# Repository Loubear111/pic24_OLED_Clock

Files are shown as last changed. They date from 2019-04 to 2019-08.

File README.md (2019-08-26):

# pic24_OLED_Clock
A RTC and OLED project for the PIC24FJ64GA002 Microcontroller. This project uses the Adafruit 1.3" Monochrome OLED display as well as the RTC module on the PIC to create an interactive clock and stopwatch with alarm functions.
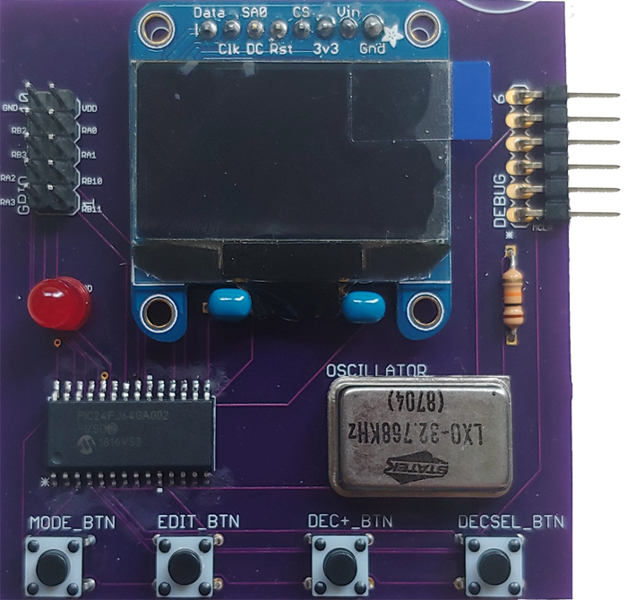
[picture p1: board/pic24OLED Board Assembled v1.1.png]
Board v1.1


**PIC24 Microcontroller** - https://www.microchip.com/wwwproducts/en/PIC24FJ64GA002 \
**Adafruit Display** - https://www.adafruit.com/product/938 \
**chipKIT Programmer** - https://store.digilentinc.com/chipkit-pgm-programmer-debugger-for-use-with-digilent-chipkit-platforms/

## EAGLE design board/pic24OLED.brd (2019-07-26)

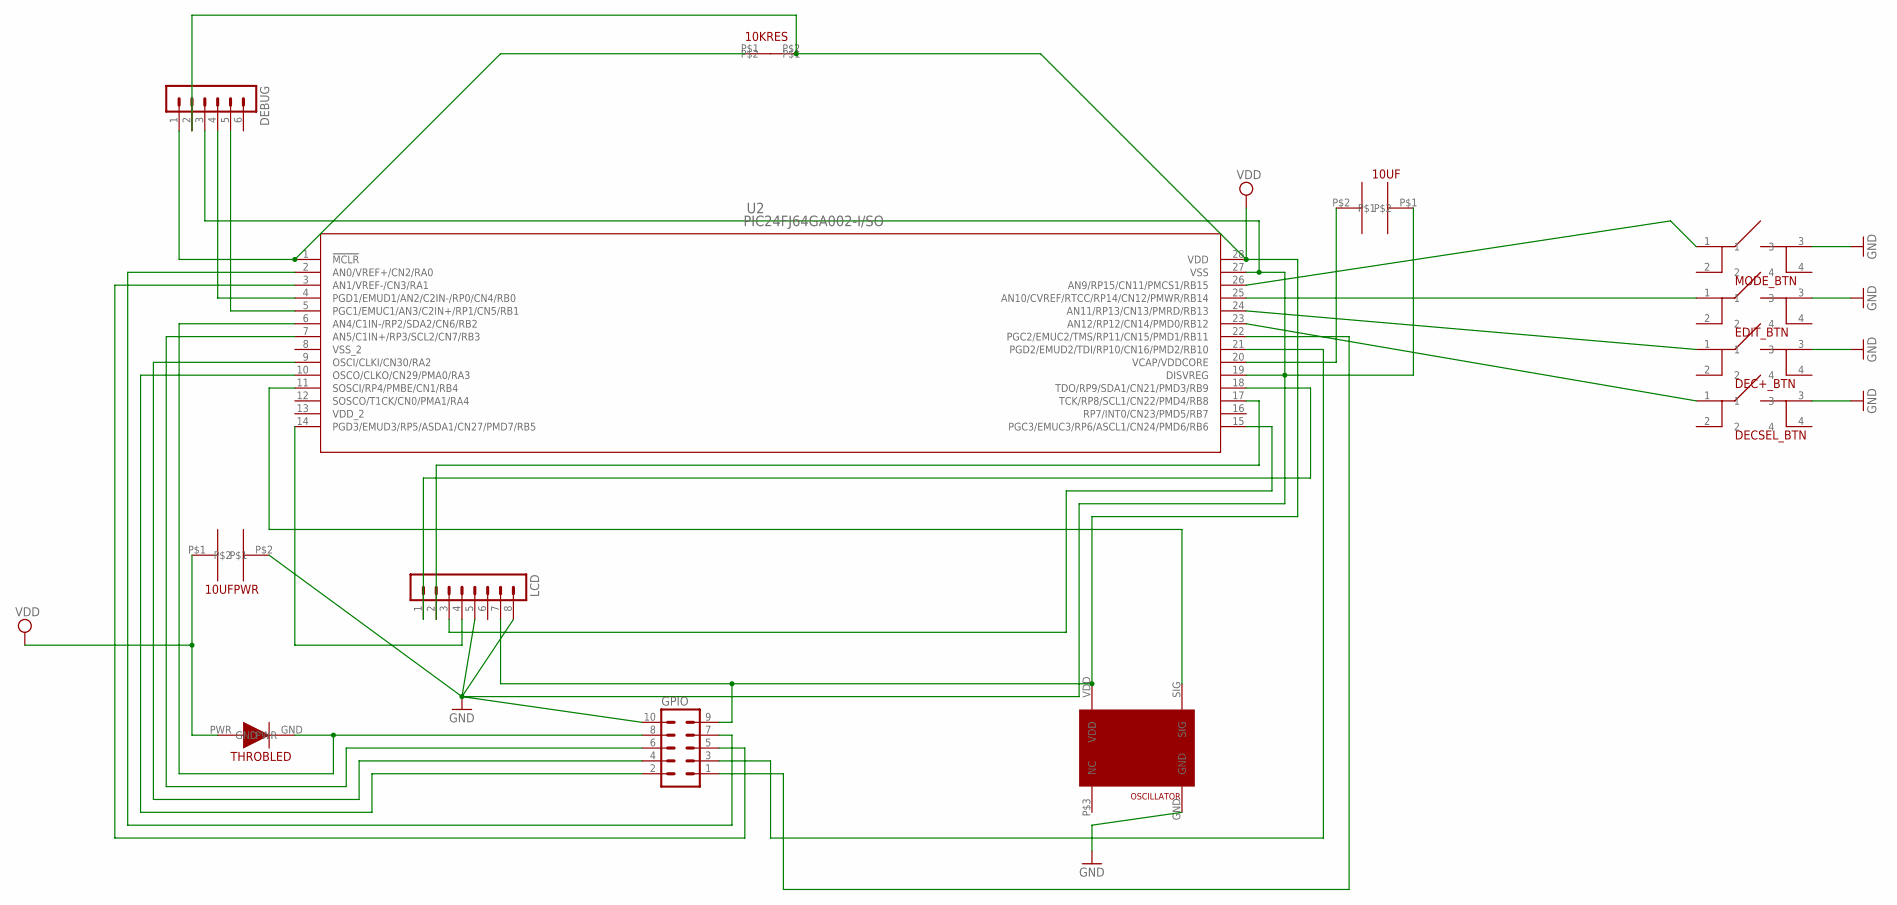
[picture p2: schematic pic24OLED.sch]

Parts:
10KRES: THRESISTOR
10UF, 10UFPWR: THCAP
DEBUG: MA06-1
DEC+_BTN: PTS645-BUTTONPTS645; TL3315-BUTTON
DECSEL_BTN: PTS645-BUTTONPTS645; TL3315-BUTTON
EDIT_BTN: PTS645-BUTTONPTS645; TL3315-BUTTON
GPIO: MA05-2
LCD: MA08-1
MODE_BTN: PTS645-BUTTONPTS645; TL3315-BUTTON
OSCILLATOR: LX0-32.768OSCILLATOR
THROBLED: THLED
U2: PIC24FJ64GA002-I/SO; SOIC28-W_MC

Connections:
GND: 10UF.P$1, 10UFPWR.P$2, DEBUG.3, DEC+_BTN.3, DECSEL_BTN.3, EDIT_BTN.3, GPIO.10, LCD.5, LCD.8, MODE_BTN.3, OSCILLATOR.GND, U2.19 (DISVREG), U2.27 (VSS)
unnamed: 10KRES.P$1, DEBUG.1, U2.1 (!MCLR)
unnamed: GPIO.4, U2.9 (OSCI/CLKI/CN30/RA2)
unnamed: MODE_BTN.1, U2.26 (AN9/RP15/CN11/PMCS1/RB15)
unnamed: EDIT_BTN.1, U2.25 (AN10/CVREF/RTCC/RP14/CN12/PMWR/RB14)
unnamed: DEC+_BTN.1, U2.24 (AN11/RP13/CN13/PMRD/RB13)
unnamed: DECSEL_BTN.1, U2.23 (AN12/RP12/CN14/PMD0/RB12)
unnamed: LCD.4, U2.14 (PGD3/EMUD3/RP5/ASDA1/CN27/PMD7/RB5)
unnamed: LCD.3, U2.15 (PGC3/EMUC3/RP6/ASCL1/CN24/PMD6/RB6)
unnamed: LCD.2, U2.17 (TCK/RP8/SCL1/CN22/PMD4/RB8)
unnamed: LCD.1, U2.18 (TDO/RP9/SDA1/CN21/PMD3/RB9)
unnamed: 10UF.P$2, U2.20 (VCAP/VDDCORE)
unnamed: GPIO.6, U2.7 (AN5/C1IN+/RP3/SCL2/CN7/RB3)
unnamed: OSCILLATOR.SIG, U2.11 (SOSCI/RP4/PMBE/CN1/RB4)
unnamed: GPIO.8, THROBLED.GND, U2.6 (AN4/C1IN-/RP2/SDA2/CN6/RB2)
unnamed: DEBUG.4, U2.4 (PGD1/EMUD1/AN2/C2IN-/RP0/CN4/RB0)
unnamed: DEBUG.5, U2.5 (PGC1/EMUC1/AN3/C2IN+/RP1/CN5/RB1)
unnamed: GPIO.2, U2.10 (OSCO/CLKO/CN29/PMA0/RA3)
unnamed: GPIO.7, U2.2 (AN0/VREF+/CN2/RA0)
unnamed: GPIO.5, U2.3 (AN1/VREF-/CN3/RA1)
unnamed: GPIO.3, U2.21 (PGD2/EMUD2/TDI/RP10/CN16/PMD2/RB10)
unnamed: GPIO.1, U2.22 (PGC2/EMUC2/TMS/RP11/CN15/PMD1/RB11)
VDD: 10KRES.P$2, 10UFPWR.P$1, DEBUG.2, GPIO.9, LCD.7, OSCILLATOR.VDD, THROBLED.PWR, U2.28 (VDD)

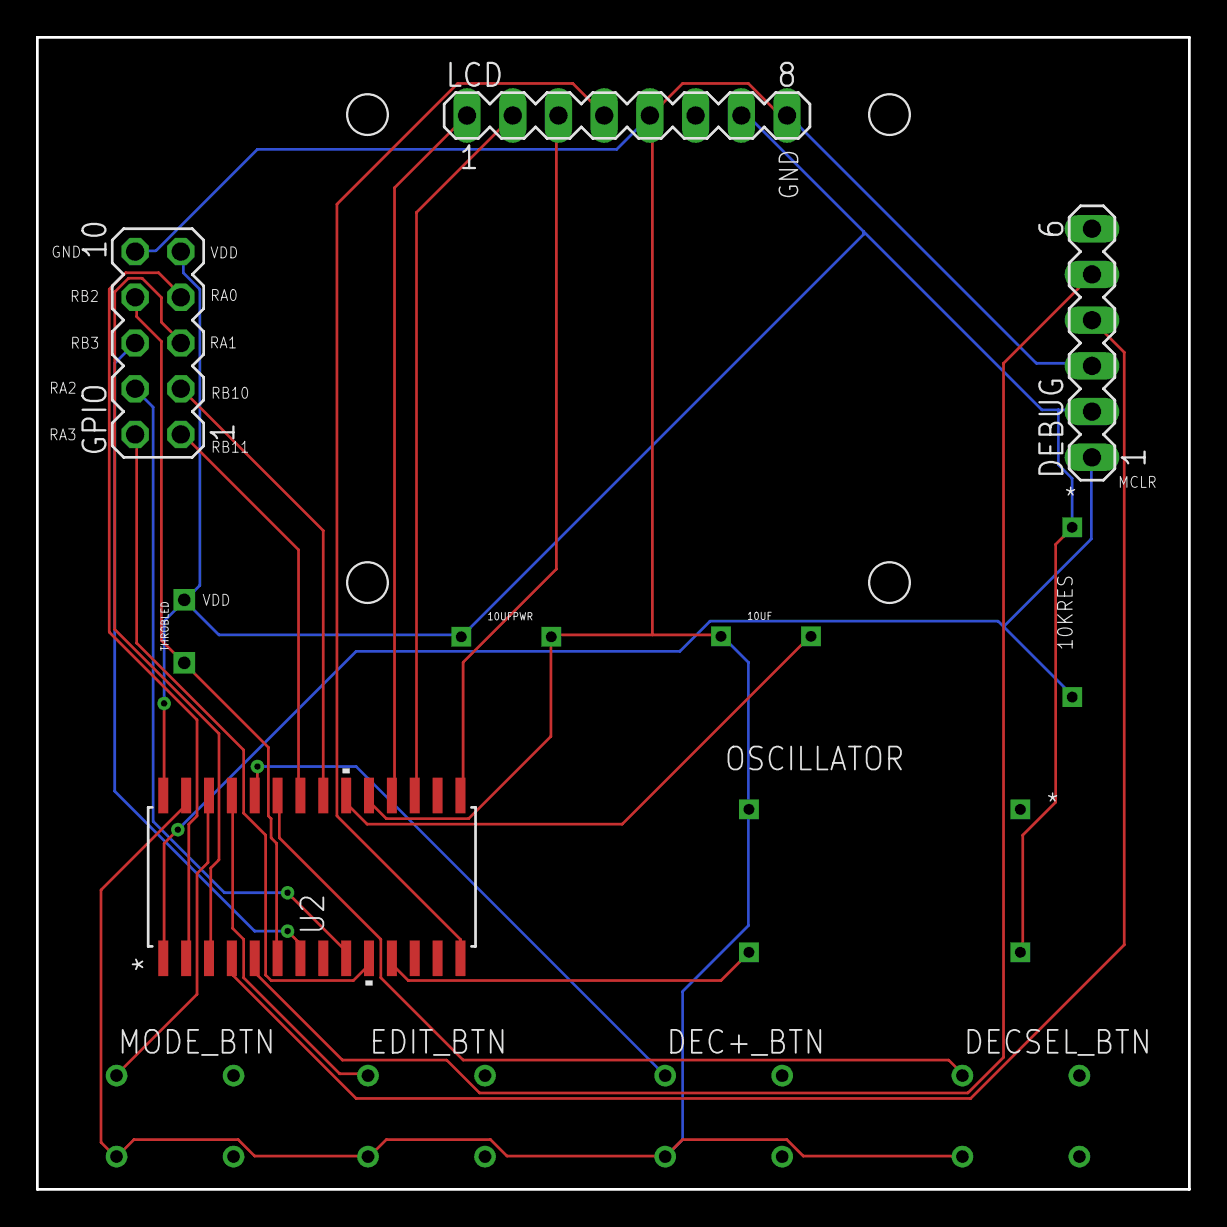
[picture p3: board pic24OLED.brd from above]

Board: 2 copper layers, 64.0 x 64.0 mm, 13 parts (0 on the bottom side), 23 nets.

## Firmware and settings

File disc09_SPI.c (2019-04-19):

#include <p24Fxxxx.h>
#include <xc.h>
#include <stdlib.h>

// PIC24FJ64GA002 Configuration Bit Settings
// CW1: FLASH CONFIGURATION WORD 1 (see PIC24 Family Reference Manual 24.1)
#pragma config ICS = PGx1          // Comm Channel Select (Emulator EMUC1/EMUD1 pins are shared with PGC1/PGD1)
#pragma config FWDTEN = OFF        // Watchdog Timer Enable (Watchdog Timer is disabled)
#pragma config GWRP = OFF          // General Code Segment Write Protect (Writes to program memory are allowed)
#pragma config GCP = OFF           // General Code Segment Code Protect (Code protection is disabled)
#pragma config JTAGEN = OFF        // JTAG Port Enable (JTAG port is disabled)


// CW2: FLASH CONFIGURATION WORD 2 (see PIC24 Family Reference Manual 24.1)
#pragma config POSCMOD = NONE           // Primary Oscillator Select (Primary oscillator disabled. 
					// Primary Oscillator refers to an external osc connected to the OSC1 and OSC2 pins)
#pragma config I2C1SEL = PRI       // I2C1 Pin Location Select (Use default SCL1/SDA1 pins)
#pragma config IOL1WAY = OFF       // IOLOCK Protection (IOLOCK may be changed via unlocking seq)
#pragma config OSCIOFNC = ON       // OSC2/CLKO/RC15 functions as port I/O (RC15)
#pragma config FCKSM = CSECME      // Clock Switching and Monitor (Clock switching is enabled, 
                                       // Fail-Safe Clock Monitor is enabled)
#pragma config FNOSC = FRCPLL      // Oscillator Select (Fast RC Oscillator with PLL module (FRCPLL))

#define DACMASK 0x1FFF
#define DACBITS 0x1000

volatile unsigned short int sample = DACBITS;

//Generic delay function
void delay(unsigned int ms)
{
    while(ms > 0)
    {
        asm("repeat #15993");
        asm("nop");
        ms--;
    }
}

void __attribute__((__interrupt__,__auto_psv__)) _T2Interrupt(void)
{
    sample &= DACMASK;
    sample |= DACBITS;

    IFS0bits.T2IF = 0;
    SPI1BUF = sample;   // Kickstart the SPI transaction. Do not worry about
                        // LDAC' now. We will get the SPI interrupt once
                        // the last bit is out. We will generate a pulse 
                        // on the LDAC' line then.
    
    sample += 41;       // the next "step" value.
}

void __attribute__((__interrupt__,__auto_psv__)) _SPI1Interrupt(void)
{
    int temp;
    _SPI1IF = 0;
    temp = SPI1BUF; // just to clear the buffer and avoid setting off the 
                    // overflow bit
    LATBbits.LATB6 = 0;  // SPI transaction complete, give a low pulse on LDAC'
        // to load the value from the input latch register to the DAC register.
    // The DAC datasheet says that the pulse has to remain low for at least
    // 100ns (p6 of the manual, the second table)
    asm("nop");
    asm("nop");
    LATBbits.LATB6 = 1;
}

void setup(void)
{
    CLKDIVbits.RCDIV = 0;
    AD1PCFG = 0x9fff;  // For digital I/O.  If you want to use analog, you'll
                       // need to change this.
    TRISB = 0;    // make all PORTBbits outputs initially

    // add your configuration commands below
    PORTB = 0xffff;
    TRISBbits.TRISB6 = 0; // Heartbeat LED
    //TRISBbits.TRISB4 = 0; // SCK
    //TRISBbits.TRISB5 = 0; // SDO
    //TRISBbits.TRISB6 = 0; // this will be the DAC /LDAC. I assume /CS is hardwired to GND

    T2CON = 0;
    PR2 = 362; // Period of step will be 363 Tcy = 22.7 us
    //T2CONbits.TON = 1;

    // Peripheral Pin Select 
    // Ver 1.25 or later
    __builtin_write_OSCCONL(OSCCON & 0xbf); // unlock PPS
    RPOR2bits.RP5R = 7;   //RB5->SPI1:SDO1; See Table 10-3 on P109 of the datasheet
    RPOR2bits.RP4R = 8;   //RB4->SPI1:SCK1OUT;
    __builtin_write_OSCCONL(OSCCON | 0x40); // lock   PPS
    
    SPI1CON1 = 0;
    SPI1CON1bits.MSTEN = 1;  // master mode
    SPI1CON1bits.MODE16 = 1; // sixteen bits
    SPI1CON1bits.CKE = 1;
    SPI1CON1bits.CKP = 0;
    SPI1CON1bits.SPRE = 0b110; // secondary prescaler = 2
    SPI1CON1bits.PPRE = 0b11;  // primary prescaler = 1;
    // SPI1CON1bits.PPRE = 0b01;  // primary prescaler = 16;
    SPI1CON2 = 0;
    SPI1STAT = 0;
    SPI1STATbits.SISEL = 0b101; // IF set when last bit is shifted out
                                // That means the SPI xfer is complete.
    //SPI1STATbits.SPIEN = 1;


    IFS0bits.T2IF = 0;
    TMR2 = 0;

    IPC1bits.T2IP = 5;
    IEC0bits.T2IE = 1;
    _SPI1IF = 0;
    _SPI1IE = 1;
}

int main(int argc, char *argv[])
{
    setup();

    while (1)
    {
       PORTBbits.RB6 = 1;
       delay(100);
       PORTBbits.RB6 = 0;
       delay(100);
    }

    return 0; // never reached (we hope)
}

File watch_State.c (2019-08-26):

#include "xc.h"
#include "util.h"
#include "lcd.h"
#include "rtc.h"
#include <math.h>
#include <stdlib.h>
#include <stdio.h>
#include <string.h>

/*
 * This is the variables I use to monitor state and edit mode. These should be passed into the display so that the display can handle all the rtc stuff.
 */
volatile int state = 0; //face will go from 0,1,2 with 0 = clock, 1 = alarm, 2 = stopwatch
volatile int prevState = 0;
volatile int prevEditState = 0;
volatile int edit = 0; //the edit will be set to off and will trigger

// boolean determine if we've debounced (we only debounce one at a time)
// 1 = timeout complete
// 0 = timeout incomplete
volatile unsigned short buttonDebounceTimeout = 1;
volatile unsigned short buttonHoldTimeout = 1;

volatile int editSel = 0;
volatile int incB = 0;
volatile int alarmEnable = 0;
static unsigned char AHOUR = 0; 
static unsigned char AMINUTE = 0; 
//static volatile int ASECOND = 0;

volatile int t1Flag = 0;
int stopWatchToggle = 0;

void button_StartNonBlockingDelay(int ms);
void check_Alarm(void);
void Stopwatch_updateTime(void);
void Reset_Stopwatch(void);
void Start_Stop_Stopwatch(void);

volatile unsigned long int StopwatchOverflow = 0; 

void __attribute__((__interrupt__,__auto_psv__)) _T1Interrupt(void)
{
    t1Flag = 1;
    StopwatchOverflow++;
    IFS0bits.T1IF = 0;
}

void __attribute__((__interrupt__,__auto_psv__)) _T2Interrupt(void)
{
    buttonDebounceTimeout = 1;
    IFS0bits.T2IF = 0;
    T2CONbits.TON = 0;
    TMR2 = 0;
}
/*
 * 
 * 
 * this function when given a button (int button) will test to see
 * if that button is being clicked. If the first or second button 
 * are clicked it will update their respective variables. The FIRST 
 * one being which face you are looking at and the SECOND one being
 * edit or normal mode. The THIRD and FOURTH button are responsible for 
 * functions within the clock face and the alarm face or during the edit face
 * and hence will not always need to be checked.
 * 
 * 
 */
int checkButton(int button)
{
    static short buttonState[] = {0, 0, 0, 0};
    static short buttonIsClick = 0;
    static short buttonControlLock = 0;
    
    if(button == 1)
    {
        if(buttonControlLock == 1 || buttonControlLock == 0)
        {
            if(!PORTBbits.RB15)
            {
                // lock down button state machine to focus on this button
                buttonControlLock = 1;

                // button was just pressed, we need to wait for release now
                if(buttonState[0] == 0 && buttonDebounceTimeout)
                {
                    buttonState[0] = 1;
                    //button_StartNonBlockingDelay(50);
                    return 0;
                }    
                return 0;
            }
            else
            {
                if(buttonState[0] == 1 && buttonDebounceTimeout)
                {
                    button_StartNonBlockingDelay(20);
                    buttonIsClick = 1;
                    buttonState[0] = 0;
                    return 0;
                }

                if(buttonState[0] == 0 && buttonDebounceTimeout && buttonIsClick)
                {
                    buttonIsClick = 0;

                    // release state machine from this button
                    buttonControlLock = 0;

                    return 1;
                }
            }
            return 0; 
        }
        return 0;
    }
    else if(button == 2)
    {
        if(buttonControlLock == 2 || buttonControlLock == 0)
        {
            if(!PORTBbits.RB14)
            {
                // lock down button state machine to focus on this button
                buttonControlLock = 2;

                // button was just pressed, we need to wait for release now
                if(buttonState[1] == 0 && buttonDebounceTimeout)
                {
                    buttonState[1] = 1;
                    //button_StartNonBlockingDelay(50);
                    return 0;
                }    
                return 0;
            }
            else
            {
                if(buttonState[1] == 1 && buttonDebounceTimeout)
                {
                    button_StartNonBlockingDelay(20);
                    buttonIsClick = 1;
                    buttonState[1] = 0;
                    return 0;
                }

                if(buttonState[1] == 0 && buttonDebounceTimeout && buttonIsClick)
                {
                    buttonIsClick = 0;

                    // release state machine from this button
                    buttonControlLock = 0;

                    return 1;
                }
            }
            return 0; 
        }
        return 0;
    }
    else if(button == 3)
    {
        if(buttonControlLock == 3 || buttonControlLock == 0)
        {
            if(!PORTBbits.RB13)
            {
                // lock down button state machine to focus on this button
                buttonControlLock = 3;

                // button was just pressed, we need to wait for release now
                if(buttonState[2] == 0 && buttonDebounceTimeout)
                {
                    buttonState[2] = 1;
                    //button_StartNonBlockingDelay(50);
                    return 0;
                }    
                return 0;
            }
            else
            {
                if(buttonState[2] == 1 && buttonDebounceTimeout)
                {
                    button_StartNonBlockingDelay(20);
                    buttonIsClick = 1;
                    buttonState[2] = 0;
                    return 0;
                }

                if(buttonState[2] == 0 && buttonDebounceTimeout && buttonIsClick)
                {
                    buttonIsClick = 0;

                    // release state machine from this button
                    buttonControlLock = 0;

                    return 1;
                }
            }
            return 0; 
        }
        return 0;
    }
    else if(button == 4)
    {
        if(buttonControlLock == 4 || buttonControlLock == 0)
        {
            if(!PORTBbits.RB12)
            {
                // lock down button state machine to focus on this button
                buttonControlLock = 4;

                // button was just pressed, we need to wait for release now
                if(buttonState[3] == 0 && buttonDebounceTimeout)
                {
                    buttonState[3] = 1;
                    //button_StartNonBlockingDelay(50);
                    return 0;
                }    
                return 0;
            }
            else
            {
                if(buttonState[3] == 1 && buttonDebounceTimeout)
                {
                    button_StartNonBlockingDelay(20);
                    buttonIsClick = 1;
                    buttonState[3] = 0;
                    return 0;
                }
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

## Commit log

2019-04-22 Initial working code. Can write bits to the display!
    First working version of the code. SPI communicates correctly with the display. Had to make sure SPI was communicating in 8 bit segments rather than the default 16 bit segments.
    [OLED_Clock_main.c]
2019-04-25 Ported LCD functions to a standalone library
    We can now write strings to the LCD at given x and y values. Currently can only write numbers 1-9.
2019-05-01 Fully functioning RTC
    RTC is now fully implemented with our handy external 32.768 kHz clock from Ax-Man. Now all we need to do is implement the currently skeleton-of-a-state-machine into a fully functioning state machine.
2019-05-03 Got setting of time setup correctly
    [OLED_Clock_main.c, watch_State.c]
2019-05-08 Fixes few small glitches with edit mode.
    [watch_State.c]
2019-06-27 Added first draft of board schematics to repo
    [pic24OLED.brd, pic24OLED.sch]
2019-06-27 Finished up first board draft completely.
    [pic24OLED.brd, pic24OLED.sch]
2019-07-26 Board design v1.1
    Used PIC layout I can actually solder. Moved some things around for easier access and made holes bigger.
    [pic24OLED.brd, pic24OLED.sch]
2019-08-24 Removed blocking button delay code and replaced with non-blocking debounce delay.
    Buttons could still use work as the don't detect button releases. To correctly capture buttons and make them not feel clunky we'll need to use button presses/releases to tell when actions happen.
    [OLED_Clock_main.c, lcd.c, lcd.h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]
2019-08-24 Added assembled v1.1 board photo
2019-08-24 resized board image
2019-08-26 Fixed up button state machine to handle clicks rather than just presses for better feel when user clicks. Updated .gitignore.
    [watch_State.c]
